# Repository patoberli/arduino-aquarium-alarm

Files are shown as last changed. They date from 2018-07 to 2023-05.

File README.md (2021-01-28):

Documentation is outdated for Arduino MKR 1500, I need to update it.
Please check .ino file for latest information. 
Important changes: new screen, arduino_secrets.h file, slightly different cabling.

# Arduino aquarium monitor with alarm
## Arduino based aquarium alarm which checks temperature and supply voltage and alarms by SMS.

It includes a small piezo buzzer which makes alarm beeps if the temperature to high. A display that shows the current temperature and a backup battery. 

Please read the text inside the .ino sketch, there are some fields you have to modify (most importantly your mobile number).

## The design 
Please note, the temp sensor is the wrong model on this image. It also doesn't need to be attached to the breadboard, this is just for illustration!

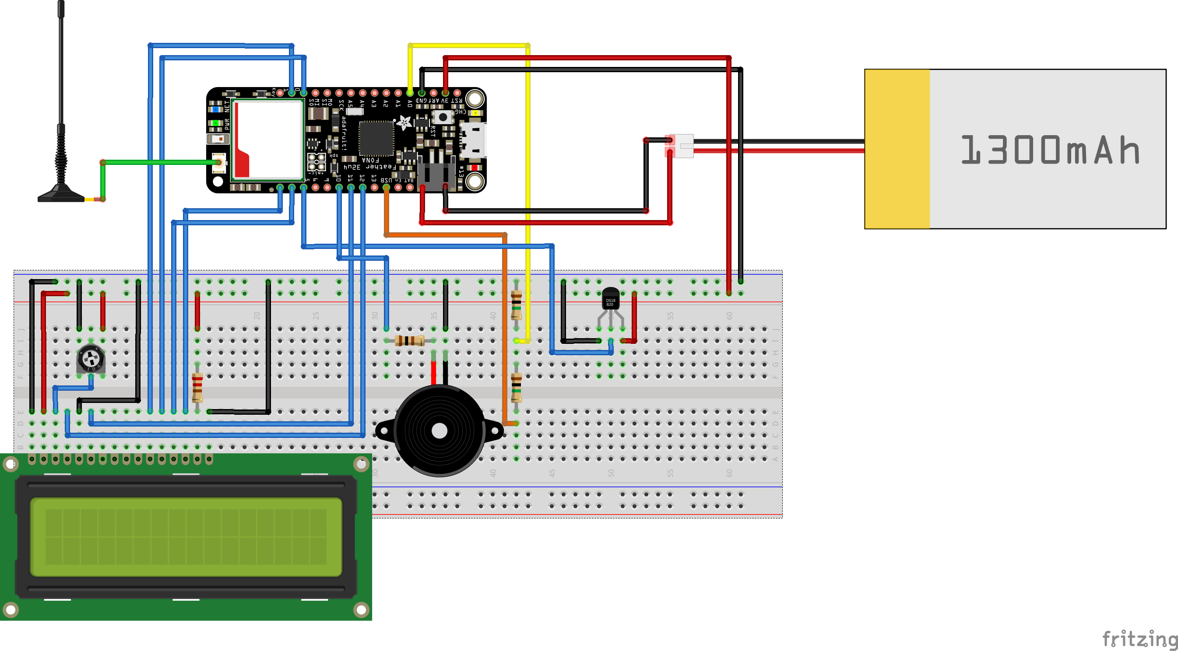
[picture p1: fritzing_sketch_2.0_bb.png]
Fritzing Design


## Required parts:
- Adafruit FONA 32u4
  - https://www.adafruit.com/product/3027
- Adafruit GSM Antenna
  - https://www.adafruit.com/product/1991
  - In my case this antenna tends to create a crash of the Arduino because of the short cable, see the FAQ of the 32u4
  - There is a variant with longer cable, I haven't tested it: https://www.adafruit.com/product/3237
  - I solved it by putting a small ferrit core around the antenna cable
- 12-pin and 16-pin feather stacking headers
  - https://www.adafruit.com/product/2830
- 500 mAh 3.7 V battery, better at least 850 mAh (to high capacity will cause long delays in the power alarm!)
  - https://www.adafruit.com/product/258 (this is the 1200 mAh model)
- micro SIM card with support for 2G (GSM), check your operators, some are starting to turn of GSM
- Breadboard with 40 or more rows
- at least 20 dupond jumper wires
- 10k resistor potentiometer for the LCD
  - https://www.arduino.cc/en/Tutorial/LiquidCrystalDisplay (PINs adjusted in this sketch, see below)
- 1602A Char LCD / 3.3V / Standard ST7066/HD44780 (must be a special 3.3V! one)
  - https://www.aliexpress.com/item/3-3V-LCD1602-LCD-monitor-1602-Blue-Screen-White-Code-Blacklight-16x2-Character-LCD-Display-Module/32453954557.html
- Piezo speaker (also known as buzzer)
- 100 Ohm resistor (for piezo)
- 220 Ohm resistor (for LCD)
- DS18B20 temp sensor with DFR0055 Plugable Terminal adapter (jumper set to Pull Up)
  - https://www.aliexpress.com/item/DS18b20-Water-Temperature-Sensor-Stainless-Steel-Probe-Temperature-Sensor-for-Arduino-SR002/32538132994.html
  - this sensor is sadly NOT salt water resistant, it requires you to protect it from direct water contact or it will quickly   corrode/rust. 
    I suggest using a tiny bit of aquarium safe silicone or synthetic resin. 
    The thicker the layer, the slower the registered temparature change, so make it thin!
  - Manual DFR0055 https://www.dfrobot.com/wiki/index.php/Terminal_sensor_adapter_V2_SKU:DFR0055

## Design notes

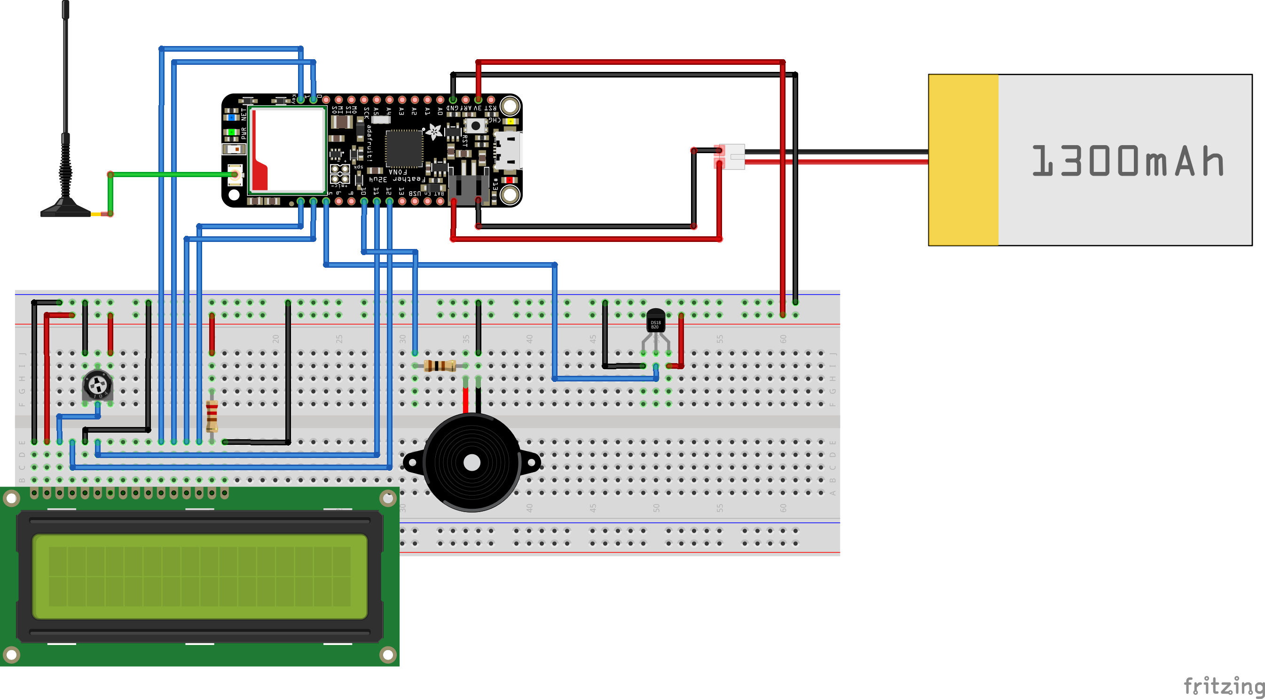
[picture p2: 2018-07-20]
fritzing_sketch_bb.png

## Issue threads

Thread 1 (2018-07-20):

Power alarm oscillating and sending several sms

patoberli, 2018-07-20:
The power alarm currently doesn't work right and causes the FONA to send way to many sms, because the voltage is oscillating for over an hour around the compared measured unit.
Will try to fix this by either clearing the variable at a "full" battery or by trying to directly monitor an input pin.

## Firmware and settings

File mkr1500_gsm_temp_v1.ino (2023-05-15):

/* Adafruit FONA GSM 32u4 module Template, massively adjusted for Arduino MKR NB 1500

modified 20230515 by Patrick Oberli

Required parts:
- Arduino MKR NB 1500 incl. antenna
	- https://store.arduino.cc/arduino-mkr-nb-1500-1413
- 1500 mAh 3.7 V battery minimum
	- https://www.adafruit.com/product/2011 (this is the 2000 mAh model)
- micro SIM card with support for 4G (LTE), check your operators
- Adafruit SSD1306 SPI Display -> this display lives for about 2 years and then can't anymore be read
- Breadboard with 40 or more rows
- at least 20 dupond jumper wires
- Piezo speaker (also known as buzzer)
- 100 Ohm resistor (for piezo)
- two > 20 kOhm resistors for USB power check
- DS18B20 temp sensor with DFR0055 Plugable Terminal adapter (jumper set to Pull Up)
	- https://www.aliexpress.com/item/DS18b20-Water-Temperature-Sensor-Stainless-Steel-Probe-Temperature-Sensor-for-Arduino-SR002/32538132994.html
	- this sensor is sadly NOT salt water resistant, it requires you to protect it from direct water contact or it will quickly corrode/rust. 
		I suggest using a tiny bit of aquarium safe silicone or synthetic resin. 
		The thicker the layer, the slower the registered temparature change, so make it thin!
	- Manual DFR0055 https://www.dfrobot.com/wiki/index.php/Terminal_sensor_adapter_V2_SKU:DFR0055
*/

// Install the libraries from the Arduino IDE Library Manager named "Adafruit SSD1306", "MKRWAN", "MKRNB" and "OneWire" (by Jim Studt, Tom Pollard, ...) 
#include <gfxfont.h>
#include <Adafruit_SPITFT_Macros.h>
#include <Adafruit_SPITFT.h>
#include <Wire.h>
//#include <USI_TWI_Master.h>
//#include <TinyWireM.h>
#include <MKRNB.h>

#include "arduino_secrets.h" 
// Please enter your sensitive data in the Secret tab or arduino_secrets.h
// If it doesn't exist, create a new file in the same directory named arduino_secrets.h
// PIN Number
const char PINNUMBER[] = SECRET_PINNUMBER;

// initialize the library instance
NB nbAccess;
NB_SMS sms;

// this is a large buffer for replies
char replybuffer[255];


/* Start SPI display */
//***************************************************************

// Install the library from Arduino IDE library manager called "OneWire" by Jim Studt, Tom Pollard, ....
#include <OneWire.h>

// SPI Display
#include <spi.h>
#include <Adafruit_GFX.h>
#include <Adafruit_SSD1306.h>

Adafruit_SSD1306 display = Adafruit_SSD1306(128, 32, &Wire);
#define OLED_RESET -1 // Reset pin # (or -1 if sharing Arduino reset pin)

/* End SPI display*/


int DS18S20_Pin = 5; //DS18S20 Signal pin on digital 5, changed from 2

//Temperature chip i/o
OneWire ds(DS18S20_Pin);  



// Modify for your own liking, number in brackets is the maximum ammount of allowed characters
char mobilenumber[20] = "+00000000000";
char messagepower[141] = "Aquarium without power!";
char messagetemp[141] = "Temperature out of range!";

int TEMPERATURESMSREQ = 0;
int TEMPERATURESMSSENT = 0;
int VOLTAGESMSREQ = 0;
int VOLTAGESMSSENT = 0;

// Audio Alarm, add a Piezo speaker to pin 10

void setup() {
	//SSD1306_SWITCHCAPVCC = generate display voltage from 3.3V internally
	display.begin(SSD1306_SWITCHCAPVCC, 0x3C); // Address 0x3C for 128x32
	Serial.println("OLED begun");

	// Show image buffer on the display hardware.
	// Since the buffer is intialized with an Adafruit splashscreen
	// internally, this will display the splashscreen.
	display.display();
	delay(1000);

	// Clear the buffer.
	display.clearDisplay();
	display.display();

	// text display tests
	display.setTextSize(1);
	display.setTextColor(SSD1306_WHITE);
	display.setCursor(0, 0);
	display.print("Temperature:");
	display.display(); // actually display all of the above

  // set LED_BUILTIN (red LED) as an output
  pinMode(LED_BUILTIN, OUTPUT);
 
  // connection state
  bool connected = false;

  // Start NB module
  // If your SIM has PIN, add it to the arduino_secrets.h file
  while (!connected) {
    if (nbAccess.begin(PINNUMBER) == NB_READY) {
      connected = true;
    } else {
      Serial.println("Not connected");
      delay(1000);
    }
  }

  Serial.println("NB initialized");

 
  delay(10000); // wait 10 seconds for everything to initialize
}


void loop() {

  // read and print the temperature to console
  float temperature = getTemp();
  Serial.print("Temperature: "); Serial.println(temperature);

  delay(100); //just here to slow down the output so it is easier to read

// set the cursor to column 0, line 10
// (note: line 10 is the elevnenth row, since counting begins with 0):
  display.clearDisplay();
  display.setCursor(0, 0);
  display.print("Temperature:");
  display.setCursor(0, 10);

  // print the temperature on the LCD:
  display.print(temperature);
  display.display();
  if (temperature >= 27) //measure if temperate is >= 27°C and produce an audio alarm if to high
  {
	  tone(10, 5000, 1000); // Audio alarm, add piezo to Pin 10, frequency 5000 Hz, 1 second beep duration
	  TEMPERATURESMSREQ = 1;
	  Serial.print("Temperature to high!: "); Serial.println(temperature);
  }
  else if (temperature <= 23) //measure if temperate is <= 23°C and produce an audio alarm if to low
  {
	  tone(10, 5000, 1000); // Audio alarm, add piezo to Pin 10, frequency 5000 Hz, 1 second beep duration
	  TEMPERATURESMSREQ = 1;
	  Serial.print("Temperature to low!: "); Serial.println(temperature);
  }
  else if (temperature <= 25.8 && temperature > 23.6) // reactivate the alarm, turn of buzzer
  {
	  noTone(10);
	  TEMPERATURESMSREQ = 0;
	  TEMPERATURESMSSENT = 0;
  }
  else {
  // do nothing, temperature is not to warm
  }
  
  while (VOLTAGESMSREQ == 1 && VOLTAGESMSSENT == 0)
  {
	  sendSMSpower();
	  VOLTAGESMSSENT = 1;
  }

  while (TEMPERATURESMSREQ == 1 && TEMPERATURESMSSENT == 0)
  {
	  sendSMStemp();
	  TEMPERATURESMSSENT = 1;
  }

  // read voltage on USB pin, to check of power is still supplied.
  // read the input on analog pin 0:
  int sensorValue = analogRead(A0);
  // Convert the analog reading (which goes from 0 - 1023) to a voltage (0 - 3.3V):
  float voltage = sensorValue * (3.3 / 1023.0);
  // print out the value you read:
  Serial.print("Measured power on USB: ");  Serial.println(voltage);

  // DEBUG stuff
  //display.clearDisplay();
  display.setCursor(80, 0);
  display.print("Voltage:");
  // set the cursor to column 90, line 10
  display.setCursor(90, 10);
  // print the temperature on the LCD, use this for debugging the voltage:
  display.print(voltage);
  display.display();

  if (voltage >= 2.40) // power ok, the 2.40 might need some fine tuning, depending on resistors and cable lengths
  {
	  digitalWrite(LED_BUILTIN, LOW);
	  VOLTAGESMSREQ = 0;
	  VOLTAGESMSSENT = 0;
	  noTone(10);
	  delay(5000);

  }
  else // no power from USB
  {
	  digitalWrite(LED_BUILTIN, HIGH);
	  VOLTAGESMSREQ = 1; // comment this while testing, to disable sending SMS
	  tone(10, 5000, 1000); // Audio alarm, add piezo to Pin 10, frequency 5000 Hz, 1 second beep duration
	  delay(4000);
  }

  // flush input
  flushSerial();

}

void sendSMSpower() {
	// send an SMS!
	flushSerial();
	Serial.println(mobilenumber);
	Serial.println(messagepower);
//	if (!fona.sendSMS(mobilenumber, messagepower)) {
//		Serial.println(F("Failed"));
//	}
//	else {
//		Serial.println(F("Sent!"));
//	}
  sms.beginSMS(mobilenumber);
  sms.print(messagepower);
  sms.endSMS();
  Serial.println("\nCOMPLETE!\n");
}

void sendSMStemp() {
	// send an SMS!
	flushSerial();
	Serial.println(mobilenumber);
	Serial.println(messagetemp);
//	if (!fona.sendSMS(mobilenumber, messagetemp)) {
//		Serial.println(F("Failed"));
//	}
//	else {
//		Serial.println(F("Sent!"));
//	}
  sms.beginSMS(mobilenumber);
  sms.print(messagetemp);
  sms.endSMS();
  Serial.println("\nCOMPLETE!\n");
}

void flushSerial() {
  while (Serial.available())
    Serial.read();
}

float getTemp() {
	//returns the temperature from one DS18S20 in DEG Celsius

	byte data[12];
	byte addr[8];

	if (!ds.search(addr)) {
		//no more sensors on chain, reset search
		Serial.println("no more sensors on chain, reset search!");
		ds.reset_search();
		return -1000;
	}

	if (OneWire::crc8(addr, 7) != addr[7]) {
		Serial.println("CRC is not valid!");
		return -1000;
	}

	if (addr[0] != 0x10 && addr[0] != 0x28) {
		Serial.print("Device is not recognized");
		return -1000;
	}

	ds.reset();
	ds.select(addr);
	ds.write(0x44, 1); // start conversion, with parasite power on at the end

	byte present = ds.reset();
	ds.select(addr);
	ds.write(0xBE); // Read Scratchpad


	for (int i = 0; i < 9; i++) { // we need 9 bytes
		data[i] = ds.read();
	}

	ds.reset_search();

	byte MSB = data[1];
	byte LSB = data[0];

	float tempRead = ((MSB << 8) | LSB); //using two's compliment
	float TemperatureSum = tempRead / 16;

	return TemperatureSum;

}

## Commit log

2018-07-20 Add all files to repository
    [fritzing_sketch.fzz]
2018-07-24 New design with alternative power measurement
    [fritzing_sketch_2.0.fzz]
2018-07-27 Corrected wiring from display to Pin0 and Pin1
2018-07-27 Fixed fritzing for corrected wiring
    [fritzing_sketch_2.0.fzz]
2021-01-28 Add files via upload
    Completely new version, based on Arduino MKR 1500 LTE model, as GSM is being phased off.
2023-05-15 Update mkr1500_gsm_temp_v1.ino
    Extended temperature alarm to also include to low temperature and a missing library.
    [mkr1500_gsm_temp_v1.ino]
